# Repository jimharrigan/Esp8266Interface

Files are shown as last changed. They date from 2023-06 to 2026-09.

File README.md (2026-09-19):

# Esp8266Interface

A WiFi bridge between a dry-contact (or opto-isolated) signal and MQTT / HTTP, built
around an ESP-01 module. It reports the state of an external input to an MQTT topic
and/or a pair of webhook URLs, and drives a relay output in response to MQTT messages
or a polled URL.

Typical use is retrofitting network connectivity onto existing wired equipment —
a doorbell transformer, an alarm panel output, a gate contact — without modifying it.

The repository contains both halves of the project:

| Path | Contents |
| --- | --- |
| `Esp8266Interface.ino` | The Arduino firmware (single sketch) |
| `Esp8266Interface/` | KiCad schematic and PCB for the carrier board |
| `Esp8266Interface/production/` | Fabrication output: gerbers, BOM, positions, IPC netlist |
| `Esp8266Interface.sln`, `*.vcxproj` | Visual Studio + [Visual Micro](https://www.visualmicro.com/) project |
| `Esp8266Interface/test/` | Scratch KiCad project, not part of the build |

## How it works

**Input → network.** An external signal pulls `GPIO3` low, either through the on-board
PC817 optocoupler (from the `HV In` header) or by a plain contact closure on the `In3`
header. A pin-change interrupt records the new level; the main loop notices the change
and:

- publishes `Trigger` (pin low) or `Reset` (pin high) to the configured MQTT topic, and
- issues an HTTP `GET` to the configured trigger URL or reset URL.

**Network → output.** The firmware subscribes to a control topic. A payload of `1` or
`trigger` drives `GPIO1` high; anything else drives it low. `GPIO1` gates a 2N7000
low-side switch on the `Rly` header, so this is intended to energise a relay coil. The
new state is echoed back to the status topic as `Output 1` / `Output 0`.

The same output can instead — or as well — be driven by polling. If a control URL is
configured, the board fetches it every 2 s and looks at the reply: a body containing
`Trigger` closes the relay, one containing `Reset` opens it. This suits a far end that
has no MQTT broker and cannot reach in to the board, only be asked.

## Hardware

### Connectors

Silkscreen labels come from the BOM; the descriptions below are derived from the netlist.

| Ref | Label | Function |
| --- | --- | --- |
| J1 | `ESP01` | 2x4 socket for the ESP-01 module |
| J4 | `Pin` | **Power in.** Pin 1 GND, pin 2 raw DC into the LM1084-3.3 regulator |
| J5 | `Pout` | **Power out.** Pin 1 raw input rail, pin 2 regulated +3.3 V |
| J7 | `HV In` | **Isolated sense input.** Pin 1 is the common return; pin 2 feeds the optocoupler through R2 (1 k), pin 3 through R3 (68 k) + R2 for a higher-voltage source. D2 (1N4004) rectifies, so an AC source works; D1 (zener) and C5 clamp and smooth what reaches the PC817 LED via R1 (2.2 k) |
| J2 | `In3` | **Non-isolated input.** Shorting the two pins pulls `GPIO3` to GND, in parallel with the optocoupler |
| J3 | `In` | **Config-portal button.** Shorts `GPIO0` to `GPIO2`, which the firmware holds low after boot |
| J6 | `Rly` | **Relay output.** Pin 1 is the raw input rail, pin 2 the 2N7000 drain; D3 (1N4001) is the flyback diode across the coil |
| SW1 | — | Momentary **reset** for the ESP-01 (`RST` to GND) |

The zener D1 has no value in the BOM, so the usable voltage range of each `HV In` tap
depends on the part actually fitted. Work out the range for your source before relying
on it, and treat anything on `HV In` as hazardous unless you know otherwise — nothing on
the board isolates `HV In` from its own source, only from the ESP side.

### ESP-01 pin usage

| Pin | Direction | Use |
| --- | --- | --- |
| `GPIO0` | input, 3.3 k pull-up (R6) | Config-portal button, read in `loop()`; also the ESP-01 flash-mode strap |
| `GPIO1` | output | Relay drive, through R4 (47 k) into the 2N7000 gate. Also the UART TX pin |
| `GPIO2` | output, driven low | Return path for the `GPIO0` button, so the button cannot hold the board in flash mode at boot. 3.3 k pull-up (R5) |
| `GPIO3` | input, internal pull-up | Sense input, from the optocoupler or `In3`. Also the UART RX pin |

Two pins do double duty as the serial port, which shapes the firmware:

- `Serial.begin()` is called with `SERIAL_TX_ONLY` so `GPIO3` stays usable as an input.
- `GPIO1` cannot be the UART TX pin and the relay drive at the same time. The
  `DEBUG_SERIAL` switch at the top of the sketch picks one:

  | `DEBUG_SERIAL` | Behaviour |
  | --- | --- |
  | `0` (default) | Boot messages print, then `setup()` calls `Serial.end()` and claims `GPIO1` as an output. Logging stops; the relay works |
  | `1` | Serial logging stays on for the whole run; the relay output does nothing |

  Use `DBG_PRINT()` / `DBG_PRINTLN()` for any log line added after boot — plain
  `Serial` calls past the end of `setup()` go to a closed port in the default build.
- `GPIO1` toggles as TX during boot. C1 (33 µF) on the MOSFET gate with R4 gives roughly
  a 1.5 s time constant, which stops the relay chattering while the module starts up —
  at the cost of the output switching slowly.

## Building and flashing

The sketch targets the Arduino core for ESP8266 and needs these libraries:

- [WiFiManager](https://github.com/tzapu/WiFiManager) (tzapu)
- [ArduinoJson](https://arduinojson.org/) v6 — the sketch uses `DynamicJsonDocument`
- [PubSubClient](https://github.com/knolleary/pubsubclient)
- `LittleFS`, `ESP8266HTTPClient`, `WiFiClientSecure` — all part of the ESP8266 core

Build with the Arduino IDE, `arduino-cli`, or the supplied Visual Studio / Visual Micro
solution. Choose a flash layout that includes a LittleFS partition — the configuration
is stored in `/config.json` and there is nowhere to save settings without it.

The board has no USB interface and no auto-reset circuit. To flash, use an external
3.3 V USB-to-serial adapter on the ESP-01's `TX`/`RX`/`GND`, hold `GPIO0` low, and pulse
reset. Doing this with the module out of the socket avoids back-feeding the `Rly` and
`HV In` circuitry through `GPIO1` and `GPIO3`.

## Configuration

At boot the board tries the WiFi credentials WiFiManager has stored, giving up after
20 s. Failing to connect is not fatal — it keeps running while the ESP8266 keeps
retrying WiFi in the background — and it deliberately does **not** open the config
portal on its own, so a router outage cannot leave an access point running unattended
in someone's wall. If WiFi stays down for 5 minutes the board reboots (see
[Failure handling](#failure-handling)).

The portal is opened on demand instead. Press the button on `J3` and the board comes up
as an access point named **`ESP`** with the password **`1234567890`**, which is also how
you configure it on first boot, when nothing is stored yet. The portal offers the
standard WiFi and info pages plus a `param` page with these fields:

| Field | Stored as | Notes |
| --- | --- | --- |
| mqtt server | `mqtt_server` | Leave empty to disable MQTT entirely |
| mqtt port | `mqtt_port` | Defaults to 8883 |
| mqtt username | `mqtt_username` | |
| mqtt password | `mqtt_password` | |
| mqtt topic | `mqtt_topic` | Status topic the board publishes to |
| mqtt control topic | `mqtt_control_topic` | Subscribed topic for output commands; leave empty to skip |
| Trigger Url | `trigger_url` | Fetched when the input goes low, at boot if it is low, and every 10 minutes while it stays low |
| Reset Url | `reset_url` | Fetched when the input goes high, at boot if it is high, and every 10 minutes while it stays high |
| Control Url | `control_url` | Polled every 2 s for the output state; leave empty to skip |

Settings are written to `/config.json` in LittleFS and reloaded at boot. The portal
timeout is 300 s and runs non-blocking, so the rest of the loop keeps running while it
is open. Saving MQTT settings takes effect immediately: the client is re-pointed at the
new broker and any live session is dropped, so the next reconnect picks up the new
server, port, credentials and control topic without a restart.

### Messages

| Direction | Topic | Payload |
| --- | --- | --- |
| Published | `mqtt_topic` | `Trigger` when the input goes low, `Reset` when it goes high, and the current state each time the broker connection comes up |
| Published | `mqtt_topic` | `Output 1` / `Output 0` after a control message |
| Subscribed | `mqtt_control_topic` | `1` or `trigger` turns the output on; any other payload turns it off |

Payload matching is case-insensitive. An HTTP request counts as successful if the
server answers with any 2xx status; the response body is only read for the control URL.

### Control URL

A control URL is polled every 2 s and the reply decides where the output sits:

| Reply body | Effect |
| --- | --- |
| contains `Trigger` | Output on — relay energised |
| contains `Reset` | Output off |
| contains both | Treated as `Trigger` |
| contains neither | Output left as it is |
| request failed | Output left as it is |

The match is case-insensitive and anywhere in the body, so a page carrying other
markup around the word still works. Only `Output 1` / `Output 0` transitions are
published to the status topic — a poll that finds the same state as last time is
silent, so a 2 s poll does not flood the broker.

Nothing about the poll reboots the board: a control URL that stops answering leaves
the relay where it was rather than dropping it, and the next poll tries again. The
request timeout is 1.5 s, under the 2 s interval, so an unreachable server cannot
stall the loop for longer than one period, and the interval is measured from the end
of each request rather than the start. The poll runs on the first pass through the
loop, so a reboot picks the output back up immediately instead of waiting, and is
held off entirely while the config portal is open, so a bad URL can still be
corrected.

Note that the request is plain HTTP over `WiFiClient` — an `https://` control URL will
not work, and the reply is trusted as-is.

MQTT runs over `WiFiClientSecure`, but `setInsecure()` is called, so the server
certificate is not validated. Credentials are stored in plaintext in the filesystem.
Treat this as suitable for a trusted LAN, not the open internet.

### Failure handling

The input is read at boot, so its state is sent even if it never changes: the matching
URL on the first pass through the loop, and the MQTT status as soon as the broker
connects.

- **URL request fails** (no WiFi, no connection, or a non-2xx reply): the next attempt
  is due 30 s later instead of 10 minutes, and when it comes due the board reboots
  instead. After the reboot it reads the input again and makes a fresh attempt.
- **WiFi down for 5 minutes:** the board reboots. The timer counts from power-up if WiFi
  never connects, so a board with no stored credentials reboots every 5 minutes until
  the portal is used.
- **MQTT disconnected:** reconnects every 5 s, but only while WiFi is up. MQTT failures
  never cause a reboot.

Neither reboot happens while the config portal is open, and the 5-minute WiFi timer
starts again when the portal closes. A reboot turns the output off until a control
message arrives; a retained control message restores it as soon as MQTT reconnects, and
a control URL restores it on the first poll.

On the ESP8266 the first software restart after a serial upload can hang in the
bootloader, so power-cycle the board once after flashing.

## Notes

The sketch compiles clean — no warnings — against ESP8266 core 3.1.2 with
`--warnings all`, in both `DEBUG_SERIAL` configurations.

A few behaviours are deliberate rather than oversights:

- The config portal opens on the button's falling edge, not while it is held, and not
  on top of a portal that is already running. It never opens by itself on a failed
  connection.
- MQTT connection attempts are spaced `MQTT_RECONNECT_INTERVAL` (5 s) apart and
  skipped while WiFi is down, so they do not stall the loop. Saving settings in the
  portal resets that, so a new broker is tried on the next pass.
- `publishMessage()` honours its `retained` argument; every call site passes `true`, so
  every status message is retained.
- Both output paths go through `SetOutput()`, so they share one idea of where the
  output is. An MQTT command is acknowledged on the status topic whether or not it
  changed anything; a control URL poll only publishes when the level actually moves.
- If both a control topic and a control URL are configured, they fight: whichever
  spoke last wins, and the URL speaks every 2 s. Configure one or the other.

## License

GPL-3.0 — see [LICENSE](LICENSE).

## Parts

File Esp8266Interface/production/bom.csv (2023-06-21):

Designator | Footprint | Quantity | Value | LCSC Part #
C1 | CP_Radial_D5.0mm_P2.00mm | 1 | 33UF
C2, C4 | C_Disc_D3.8mm_W2.6mm_P2.50mm | 2 | .01
C3 | CP_Radial_D5.0mm_P2.00mm | 1 | 10UF
C5 | CP_Radial_D5.0mm_P2.00mm | 1 | 22UF
D1 | D_A-405_P5.08mm_Vertical_AnodeUp | 1 | D_Zener
D2 | D_DO-41_SOD81_P5.08mm_Vertical_KathodeUp | 1 | 1N4004
D3 | D_DO-41_SOD81_P3.81mm_Vertical_KathodeUp | 1 | 1N4001
J1 | PinHeader_2x04_P2.54mm_Vertical | 1 | ESP01
J2 | PinHeader_1x02_P2.54mm_Vertical | 1 | In3
J3 | PinHeader_1x02_P2.54mm_Vertical | 1 | In
J4 | PinHeader_1x02_P2.54mm_Vertical | 1 | Pin
J5 | PinHeader_1x02_P2.54mm_Vertical | 1 | Pout
J6 | PinHeader_1x02_P2.54mm_Vertical | 1 | Rly
J7 | PinHeader_1x03_P2.54mm_Vertical | 1 | HV In
Q1 | TO-92_Inline | 1 | 2N7000
R1 | R_Axial_DIN0207_L6.3mm_D2.5mm_P2.54mm_Vertical | 1 | 2.2k
R2 | R_Axial_DIN0207_L6.3mm_D2.5mm_P2.54mm_Vertical | 1 | 1k
R3 | R_Axial_DIN0309_L9.0mm_D3.2mm_P2.54mm_Vertical | 1 | 68K
R4 | R_Axial_DIN0207_L6.3mm_D2.5mm_P2.54mm_Vertical | 1 | 47K
R5, R6 | R_Axial_DIN0207_L6.3mm_D2.5mm_P2.54mm_Vertical | 2 | 3.3K
SW1 | SW_Tactile_Straight_KSL0Axx1LFTR | 1 | SW_Push
U1 | TO-220-3_Horizontal_TabDown | 1 | LM1084-3.3
U2 | DIP-4_W7.62mm | 1 | PC817

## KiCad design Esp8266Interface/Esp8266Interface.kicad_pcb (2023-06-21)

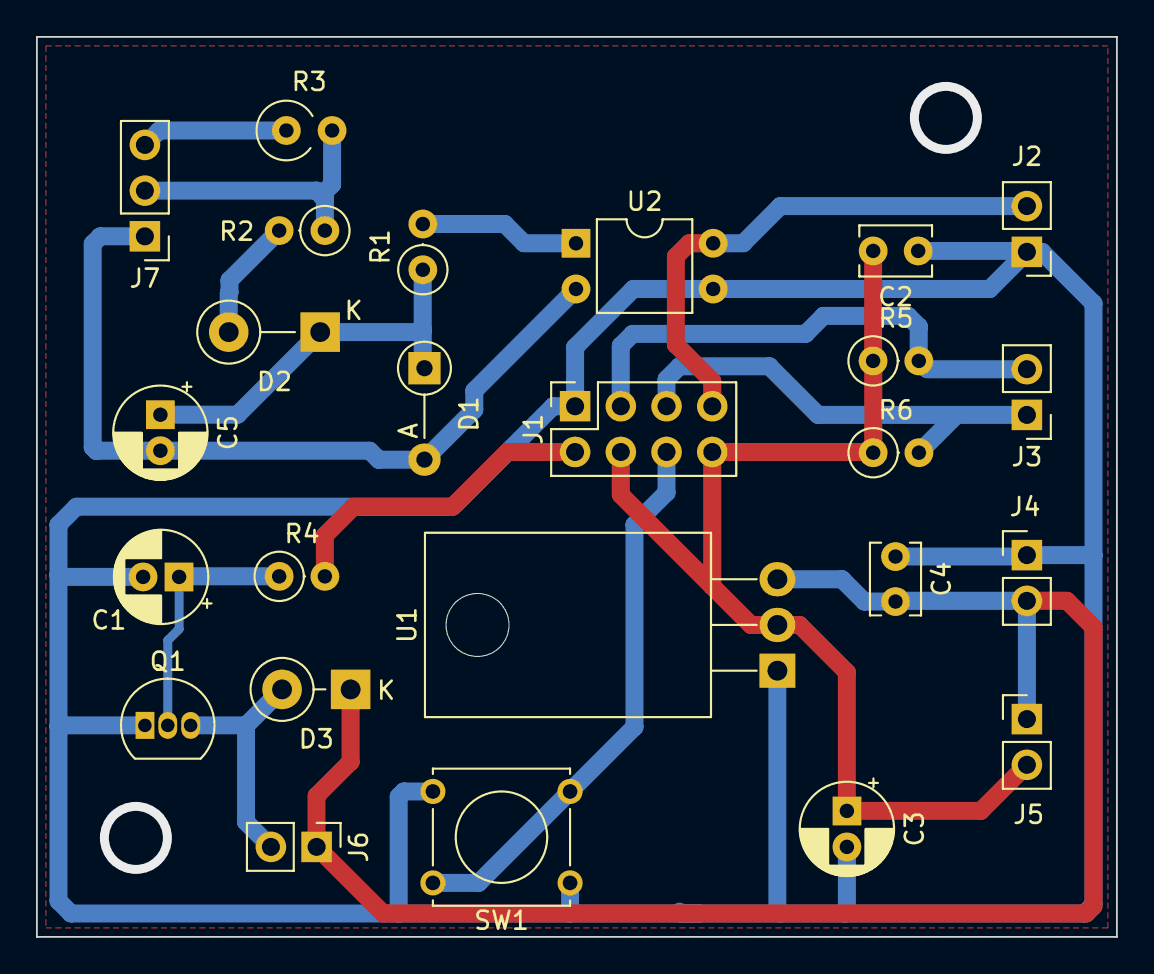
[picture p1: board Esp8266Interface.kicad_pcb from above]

Board: 2 copper layers, 60.0 x 50.0 mm, 25 parts (0 on the bottom side), 16 nets.

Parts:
C1: 33UF; CP_Radial_D5.0mm_P2.00mm
C2, C4: .01; C_Disc_D3.8mm_W2.6mm_P2.50mm
C3: 10UF; CP_Radial_D5.0mm_P2.00mm
C5: 22UF; CP_Radial_D5.0mm_P2.00mm
D1: D_Zener; D_A-405_P5.08mm_Vertical_AnodeUp
D2: 1N4004; D_DO-41_SOD81_P5.08mm_Vertical_KathodeUp
D3: 1N4001; D_DO-41_SOD81_P3.81mm_Vertical_KathodeUp
J1: ESP01; PinHeader_2x04_P2.54mm_Vertical
J2: In3; PinHeader_1x02_P2.54mm_Vertical
J3: In; PinHeader_1x02_P2.54mm_Vertical
J4: Pin; PinHeader_1x02_P2.54mm_Vertical
J5: Pout; PinHeader_1x02_P2.54mm_Vertical
J6: Rly; PinHeader_1x02_P2.54mm_Vertical
J7: HV In; PinHeader_1x03_P2.54mm_Vertical
Q1: 2N7000; TO-92_Inline
R1: 2.2k; R_Axial_DIN0207_L6.3mm_D2.5mm_P2.54mm_Vertical
R2: 1k; R_Axial_DIN0207_L6.3mm_D2.5mm_P2.54mm_Vertical
R3: 68K; R_Axial_DIN0309_L9.0mm_D3.2mm_P2.54mm_Vertical
R4: 47K; R_Axial_DIN0207_L6.3mm_D2.5mm_P2.54mm_Vertical
R5, R6: 3.3K; R_Axial_DIN0207_L6.3mm_D2.5mm_P2.54mm_Vertical
SW1: SW_Push; SW_Tactile_Straight_KSL0Axx1LFTR
U1: LM1084-3.3; TO-220-3_Horizontal_TabDown
U2: PC817; DIP-4_W7.62mm

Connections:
+3.3V: C2.2, C3.1, J1.4 (CH_PD), J1.8 (Vcc), J5.2, R5.1, R6.1, U1.2 (VO)
GND: C1.2, C2.1, C3.2, C4.1, J1.1 (GND), J2.1, J4.1, Q1.1 (S), SW1.2, U1.1 (GND), U2.3
unnamed: C5.2, D1.2 (A), J7.1, U2.2
unnamed: C5.1, D1.1 (K), D2.1 (K), R1.1
unnamed: D2.2 (A), R2.2
unnamed: D3.2 (A), J6.2, Q1.3 (D)
unnamed: C4.2, D3.1 (K), J4.2, J5.1, J6.1, U1.3 (VI)
unnamed: J1.5 (GPIO0), J3.1, R6.2
unnamed: J1.2 (GPIO1), R4.2
unnamed: J1.3 (GPIO2), J3.2, R5.2
unnamed: J1.7 (GPIO3), J2.2, U2.4
unnamed: J1.6 (Reset), SW1.1
unnamed: J7.2, R2.1, R3.2
unnamed: J7.3, R3.1
unnamed: C1.1, Q1.2 (G), R4.1
unnamed: R1.2, U2.1

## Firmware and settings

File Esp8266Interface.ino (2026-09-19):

#include <Arduino.h>
#include <FS.h>
#include <LittleFS.h>

#define start_portal_pin 0
#define output_pin 1
#define control_pin 2
#define input_pin 3

// output_pin (GPIO1) is also the UART TX pin, so serial logging and the output
// cannot both have it. Set DEBUG_SERIAL to 1 to keep logging for the whole run
// and leave the output dead, or 0 to release the UART at the end of setup() so
// the output can be driven. Boot messages are printed either way.
#define DEBUG_SERIAL 0

#if DEBUG_SERIAL
#define DBG_PRINT(x)   Serial.print(x)
#define DBG_PRINTLN(x) Serial.println(x)
#else
#define DBG_PRINT(x)
#define DBG_PRINTLN(x)
#endif

#ifdef ESP8266
#include <ESP8266WiFi.h>
#include <ESP8266HTTPClient.h>
#else
#include <WiFi.h>
#endif

#include <WiFiManager.h> // https://github.com/tzapu/WiFiManager
#include <ArduinoJson.h>
#include <PubSubClient.h>
#include <WiFiClientSecure.h>



// How long to wait between MQTT connection attempts. The initial value sits one
// interval in the past so the first attempt is not delayed.
#define MQTT_RECONNECT_INTERVAL 5000UL
unsigned long lastReconnectAttempt = (unsigned long)0 - MQTT_RECONNECT_INTERVAL;

// The trigger/reset urls are re-sent this often even when the input has not
// changed, so the far end keeps hearing the current state. setup() backdates the
// timer so the first request goes out as soon as loop() starts.
#define URL_REPEAT_INTERVAL 600000UL
unsigned long lastUrlRequest = 0;

// A request that does not get through (WiFi down, server unreachable, or a
// non-2xx reply) is followed up after this much shorter wait rather than at the
// next ten-minute repeat. The follow-up reboots the board before trying again;
// see SendStateUrl().
#define URL_RETRY_INTERVAL 30000UL
unsigned long urlRequestInterval = URL_REPEAT_INTERVAL;
bool lastUrlRequestFailed = false;

// How often the control url is polled, when one is configured. A poll is a
// blocking request, so the timeout is held below the interval to stop an
// unreachable server from stalling the loop for longer than one period.
// setup() backdates the timer so the first poll goes out as soon as loop()
// starts, which is what picks the output back up after a reboot.
#define CONTROL_URL_INTERVAL 2000UL
#define CONTROL_URL_TIMEOUT 1500UL
unsigned long lastControlUrlRequest = 0;

// The board reboots once WiFi has been down for this long. The timer starts at
// zero, so a board that never connects after power-up counts from boot.
#define WIFI_DOWN_REBOOT_INTERVAL 300000UL
unsigned long lastWifiConnected = 0;

// A contact closing or opening rattles for a few milliseconds, and every one of
// those edges raises an interrupt. The level has to hold steady for this long
// before the main loop treats it as a real change, so one flick of the input
// produces one message instead of a burst of them.
#define DEBOUNCE_INTERVAL 50UL

bool portalButtonWasPressed = false;
bool shouldSaveConfig = false;
// The debounced level the rest of the sketch acts on. setup() replaces this with
// the real level before loop() starts.
bool inputValue = 1;
// Written by the interrupt handler on every edge, bounces included, along with
// the time that edge arrived. Both are volatile because the main loop reads what
// the handler writes.
volatile bool rawInputValue = 1;
volatile unsigned long lastEdgeTime = 0;
// The level the output is being held at. Tracked so the polled control url can
// tell a real change from a repeat of the level it already set.
bool outputValue = 0;
char mqtt_server[64] = "";
int mqtt_port = 8883;
char mqtt_username[32] = "";
char mqtt_password[32] = "";
char mqtt_topic[32] = "";
char mqtt_control_topic[32] = "";
char trigger_url[64] = "";
char reset_url[64] = "";
char control_url[64] = "";

WiFiManagerParameter custom_mqtt_server("server", "mqtt server", "", 63);
WiFiManagerParameter custom_mqtt_port("port", "mqtt port", "", 6);
WiFiManagerParameter custom_mqtt_user("user", "mqtt username", "", 31);
WiFiManagerParameter custom_mqtt_password("password", "mqtt password", "", 31);
WiFiManagerParameter custom_mqtt_topic("topic", "mqtt topic", "", 31);
WiFiManagerParameter custom_mqtt_control_topic("control", "mqtt control topic", "", 31);
WiFiManagerParameter custom_trigger_url("triggerurl", "Trigger Url", "", 63);
WiFiManagerParameter custom_reset_url("reseturl", "Reset Url", "", 63);
WiFiManagerParameter custom_control_url("controlurl", "Control Url", "", 63);

/**** Secure WiFi Connectivity Initialisation *****/
WiFiClientSecure espClient;
WiFiManager wm;

// Records the input level and the moment it changed on every edge. The main loop
// does the debouncing, so this stays short. millis() is IRAM_ATTR in the esp8266
// core and is safe to call from here.
IRAM_ATTR void interruptHandler() {
  rawInputValue = digitalRead(input_pin);
  lastEdgeTime = millis();
}

/**** MQTT Client Initialisation Using WiFi Connection *****/
PubSubClient client(espClient);

/************* Connect to MQTT Broker ***********/
void reconnect() {
    if(!client.connected()) {
        DBG_PRINT("Attempting MQTT connection...");
        DBG_PRINT("mqtt_username=");
        DBG_PRINT(mqtt_username);
        DBG_PRINT("|");
        String clientId = "ESP8266Client-";   // Create a random client ID
        clientId += String(random(0xffff), HEX);
        // Attempt to connect
        if (client.connect(clientId.c_str(), mqtt_username, mqtt_password)) {
            DBG_PRINTLN("connected");

            if(strlen(mqtt_control_topic) > 0)
            {
                DBG_PRINT("Going to save->");
                DBG_PRINT(mqtt_control_topic);
                client.subscribe(mqtt_control_topic);   // subscribe the topics here
                DBG_PRINTLN("<-Done.");
            }

            // Anything that changed while the connection was down was never
            // published, so bring the retained state up to date now.
            publishMessage(mqtt_topic, inputValue ? "Reset" : "Trigger", true);

        }
        else {
            DBG_PRINT("failed, rc=");
            DBG_PRINT(client.state());
        }
    }
}

void SaveConfig()
{
    //Serial.println("Saving config...");

    JsonDocument json;

    json["mqtt_server"] = mqtt_server;
    json["mqtt_port"] = mqtt_port;
    json["mqtt_username"] = mqtt_username;
    json["mqtt_password"] = mqtt_password;
    json["mqtt_topic"] = mqtt_topic;
    json["mqtt_control_topic"] = mqtt_control_topic;
    json["trigger_url"] = trigger_url;
    json["reset_url"] = reset_url;
    json["control_url"] = control_url;
    
    if (!LittleFS.begin()) {
        //Serial.println("LittleFS Mount Failed");
        return;
    }
    File configFile = LittleFS.open("/config.json", "w");
    if (!configFile) {
        //Serial.println("failed to open config file for writing");
    }

#if DEBUG_SERIAL
    serializeJson(json, Serial);
#endif
    serializeJson(json, configFile);
    configFile.close();
    LittleFS.end();
    //end save

}

// Copy one string field out of the config document. The destination is left
// alone if the key is missing or is not a string, and an over-long value in the
// file is truncated rather than allowed to run off the end of the buffer.
static void LoadString(JsonDocument& json, const char* key, char* dest, size_t size)
{
    const char* value = json[key];
    if (value != nullptr)
    {
        strlcpy(dest, value, size);
    }
}

void LoadConfig()
{
    //Serial.println("Loading Config...");

    ////Serial.println(custom_mqtt_server.getValue());

    //read configuration from FS json
    //Serial.println("mounting FS...");

    if (LittleFS.begin()) {
        //Serial.println("mounted file system");
        if (LittleFS.exists("/config.json")) {
            //file exists, reading and loading
            //Serial.println("reading config file");
            File configFile = LittleFS.open("/config.json", "r");
            if (configFile) {
                //Serial.println("opened config file");
                JsonDocument json;
                auto deserializeError = deserializeJson(json, configFile);
#if DEBUG_SERIAL
                serializeJson(json, Serial);
#endif
                if (!deserializeError) {
                    //Serial.println("\nparsed json");

                    // A missing key leaves the field at its compiled-in default,
                    // so a config.json from an older build loads what it does
                    // have instead of faulting on the keys it lacks.
                    LoadString(json, "mqtt_server", mqtt_server, sizeof(mqtt_server));
                    mqtt_port = json["mqtt_port"] | mqtt_port;
                    LoadString(json, "mqtt_username", mqtt_username, sizeof(mqtt_username));
                    LoadString(json, "mqtt_password", mqtt_password, sizeof(mqtt_password));
                    LoadString(json, "mqtt_topic", mqtt_topic, sizeof(mqtt_topic));
                    LoadString(json, "mqtt_control_topic", mqtt_control_topic, sizeof(mqtt_control_topic));
                    LoadString(json, "trigger_url", trigger_url, sizeof(trigger_url));
                    LoadString(json, "reset_url", reset_url, sizeof(reset_url));
                    LoadString(json, "control_url", control_url, sizeof(control_url));
                }
                else
                {
                    //Serial.println("failed to load json config");
                }
                configFile.close();
            }
        }
        LittleFS.end();
    }
    else {
        //Serial.println("failed to mount FS");

        //Try to format so we can save later
        if(LittleFS.format())
        {
          //Serial.println("Format complete");
        }
        else
        {
          //Serial.println("Format failed");
        }
    }
    //end read
}

void saveParamCallback() {
    //Serial.println("saveParamCallback()");
    shouldSaveConfig = true;
}

// Drives the output and echoes the new level to the status topic. Both control
// paths go through here so they share one idea of where the output is. An
// explicit MQTT command is acknowledged whether or not it changed anything; the
// polled control url repeats the same level every couple of seconds, so it only
// publishes when the level actually moves.
void SetOutput(bool value, bool alwaysPublish)
{
    bool changed = value != outputValue;

    outputValue = value;
    digitalWrite(output_pin, value);

    if (changed || alwaysPublish)
    {
        publishMessage(mqtt_topic, value ? "Output 1" : "Output 0", true);
    }
}

/***** Call back Method for Receiving MQTT messages and Switching LED ****/

void mqttCallback(char* topic, byte* payload, unsigned int length) {
  
    String incommingMessage = "";
    for (unsigned int i = 0; i < length; i++) incommingMessage += (char)payload[i];

    DBG_PRINTLN("Message arrived [" + String(topic) + "]" + incommingMessage);
    incommingMessage.toLowerCase();
    //--- check the incomming message
    if (String(topic).equals(mqtt_control_topic)) {
        if (incommingMessage.equals("1") || incommingMessage.equals("trigger") )
        {
            //Serial.println("TRIGGER CONTROL!!!");
            SetOutput(1, true);
        }
        else
        {
          //Serial.println("RESET control");
          SetOutput(0, true);
        }
    }

}

// Returns true when the server answered with a 2xx status; no WiFi, a
// connection failure (negative httpCode) or a non-2xx status is a failure.
// A caller that cares what the server said passes a string for the body, which
// is filled in on success and emptied on failure; passing nullptr skips reading
// it. timeout bounds the connect and the read, so a server that accepts the
// connection and then goes quiet cannot hold up the loop indefinitely.
bool MakeRequest(String url, String* body, unsigned long timeout)
{
    bool success = false;

    if (body != nullptr)
    {
        *body = "";
    }

    if (WiFi.status() == WL_CONNECTED) { //Check the current connection status
        ////Serial.println("WiFi is connected");
        WiFiClient wiFiClient;
        HTTPClient http;

        http.setTimeout(timeout);
        http.begin(wiFiClient, url);
        ////Serial.print("Requesting:");
        ////Serial.println(url);
        int httpCode = http.GET();  //Make the request

        success = httpCode >= 200 && httpCode < 300;

        if (success && body != nullptr)
        {
            *body = http.getString();
        }

        http.end(); //Free the resources
    }

    return success;
}

// Fire-and-forget form, for the trigger and reset urls: any endpoint that
// accepts the request counts as a success and the body is never read.
bool MakeRequest(String url)
{
    return MakeRequest(url, nullptr, HTTPCLIENT_DEFAULT_TCP_TIMEOUT);
}

// Requests the url matching the current input level and restarts the repeat
// timer, so a repeat always lands a full interval after the last request,
// whether that came from an edge or from the timer itself. A failed request
// shortens the wait to the retry interval.
//
// If the previous request failed, the board is rebooted instead of trying
// again, clearing whatever state the WiFi stack or network client is stuck in.
// The flag lives in RAM, so the reboot clears it; setup() then reads the input
// and the first pass through loop() makes a real attempt. That attempt reboots
// only if it fails and another retry interval goes by. The reboot is skipped
// while the config portal is up, so it cannot be closed in the middle of use.
void SendStateUrl()
{
    if (lastUrlRequestFailed && !wm.getConfigPortalActive())
    {
        ESP.restart();
    }

    lastUrlRequest = millis();

    const char* url = inputValue ? reset_url : trigger_url;

    if(strlen(url) == 0)
    {
        lastUrlRequestFailed = false;
        urlRequestInterval = URL_REPEAT_INTERVAL;
        return;
    }

    //Serial.println(inputValue ? "Requesting reset_url" : "Requesting trigger_url");
    lastUrlRequestFailed = !MakeRequest(url);
    urlRequestInterval = lastUrlRequestFailed ? URL_RETRY_INTERVAL : URL_REPEAT_INTERVAL;
}

// Asks the control url what the output should be doing and does what it says.
// "Trigger" anywhere in the reply closes the relay and "Reset" opens it;
// matching is case-insensitive and the rest of the body is ignored, so a page
// carrying other text still works. A reply holding both words is taken as a
// trigger. A reply holding neither, or a request that does not get through,
// leaves the output where it is and the next poll tries again - unlike the
// state urls, a failure here neither reboots the board nor drops the relay,
// because the far end going quiet for a moment is not a command.
void PollControlUrl()
{
    String body;
    bool success = MakeRequest(control_url, &body, CONTROL_URL_TIMEOUT);

    // Timed from the end of the request rather than the start, so a slow or
    // timing-out server spaces the polls out instead of running them back to
    // back.
    lastControlUrlRequest = millis();

    if (!success)
    {
        return;
    }

    body.toLowerCase();

    if (body.indexOf("trigger") >= 0)
    {
        SetOutput(1, false);
    }
    else if (body.indexOf("reset") >= 0)
    {
        SetOutput(0, false);
    }
}

/**** Method for Publishing MQTT Messages **********/
void publishMessage(const char* topic, String payload, boolean retained) {
    if (client.publish(topic, payload.c_str(), retained))
    {
        DBG_PRINTLN("Message publised [" + String(topic) + "]: " + payload);
    }
    else
    {
      DBG_PRINTLN("Failed to publish MQTT message.");
    }
}
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
void loop() {

    wm.process(); // avoid delays() in loop when non-blocking and other long running code

    // Act on the press itself rather than on every pass while the button is
    // held, and never on top of a portal that is already up. The return value is
    // not a success flag here: the portal is non-blocking, so startConfigPortal()
    // returns the not-yet-connected state immediately.
    bool portalButtonPressed = !digitalRead(start_portal_pin);

    if (portalButtonPressed && !portalButtonWasPressed && !wm.getConfigPortalActive())
    {
        DBG_PRINTLN("Starting config portal.");
        wm.startConfigPortal("ESP", "1234567890");
    }

    portalButtonWasPressed = portalButtonPressed;

    // Reboot once WiFi has been gone for too long, in case the WiFi stack has
    // wedged rather than the network simply being down. An open config portal
    // counts as connected, so the portal is never closed mid-use and a full
    // interval is allowed after it closes. Comparing the difference keeps this
    // correct across the 49-day millis() rollover.
    if (WiFi.status() == WL_CONNECTED || wm.getConfigPortalActive())
    {
        lastWifiConnected = millis();
    }
    else if (millis() - lastWifiConnected >= WIFI_DOWN_REBOOT_INTERVAL)
    {
        ESP.restart();
    }

    if (shouldSaveConfig)
    {
        strcpy(mqtt_server, custom_mqtt_server.getValue());
        mqtt_port = atoi(custom_mqtt_port.getValue());
        DBG_PRINTLN(mqtt_port);
        strcpy(mqtt_username, custom_mqtt_user.getValue());
        strcpy(mqtt_password, custom_mqtt_password.getValue());
        strcpy(mqtt_topic, custom_mqtt_topic.getValue());
        strcpy(mqtt_control_topic, custom_mqtt_control_topic.getValue());
        strcpy(trigger_url, custom_trigger_url.getValue());
        strcpy(reset_url, custom_reset_url.getValue());
        strcpy(control_url, custom_control_url.getValue());

        SaveConfig();
        shouldSaveConfig = false;

        // Re-point the client at what was just saved. setServer() keeps the port
        // by value, so a port change is invisible without this call, and drop any
        // live session so the next reconnect() picks up the new broker,
        // credentials and control topic instead of waiting for a reboot.
        client.setServer(mqtt_server, mqtt_port);
        if (client.connected())
        {
            client.disconnect();
        }

        // Reconnect on the next pass rather than after the backoff interval, so
        // saving settings visibly takes effect. Backdating from millis() keeps
        // this correct across the 49-day rollover.
        lastReconnectAttempt = millis() - MQTT_RECONNECT_INTERVAL;
    }

    if(strlen(mqtt_server) > 0 )
    {
        if (!client.connected())
        {
            // Space the attempts out, so an unreachable broker is retried every
            // few seconds rather than as fast as connect() can time out. Without
            // WiFi an attempt cannot succeed and would only stall the loop, so
            // hold off; the timer is left alone, so the first pass after WiFi
            // returns tries straight away.
            if (WiFi.status() == WL_CONNECTED &&
                millis() - lastReconnectAttempt >= MQTT_RECONNECT_INTERVAL)
            {
                lastReconnectAttempt = millis();
                reconnect();
            }
        }
        client.loop();
    }

    // A poll blocks for as long as the request takes, so it is held off while
    // the config portal is up: an unreachable control url would otherwise stall
    // the loop for most of every interval and leave the portal too sluggish to
    // correct it with. Comparing the difference keeps this correct across the
    // 49-day millis() rollover, as elsewhere in the loop.
    if(strlen(control_url) > 0 && !wm.getConfigPortalActive() &&
       millis() - lastControlUrlRequest >= CONTROL_URL_INTERVAL)
    {
        PollControlUrl();
    }

    //Serial.print(inputValue);
    //Serial.println(inputValue ? " Reset" : " Trigger");
    // Take a consistent pair: an edge landing between these two reads would
    // otherwise pair a new level with the previous edge's timestamp and let a
    // bounce through.
    noInterrupts();
    bool pendingValue = rawInputValue;
    unsigned long pendingEdgeTime = lastEdgeTime;
    interrupts();

    // Accept the new level only once it has sat still for the debounce interval.
    // While the input is still rattling every bounce pushes lastEdgeTime forward
    // and restarts the wait, so nothing is sent until it settles, and the level
    // that gets reported is the one it settled on.
    if(pendingValue != inputValue && millis() - pendingEdgeTime >= DEBOUNCE_INTERVAL)
    {
        inputValue = pendingValue;

        if(client.connected())
        {
            publishMessage(mqtt_topic, inputValue ? "Reset" : "Trigger", true);
        }

        SendStateUrl();
    }
    else if (millis() - lastUrlRequest >= urlRequestInterval)
    {
        // No edge for a while, so repeat whichever url matches the current
        // state, or retry sooner if the last request failed. Comparing the
        // difference keeps this correct across the 49-day millis() rollover.
        SendStateUrl();
    }
}

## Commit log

2023-06-19 Add KiCad files
    [Esp8266Interface.kicad_pcb, Esp8266Interface.kicad_sch, bom.csv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]
2023-06-21 Circuit board
    [Esp8266Interface.kicad_pcb, Esp8266Interface.kicad_sch, bom.csv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]
2025-06-02 Change to use interrupts to detect changes for input_pin + old uncommitted changes
2026-09-11 Fix output pin, HTTP trigger, config loading and WiFi connect
    Four defects that each disabled or crashed a documented feature:
    Relay output never drove. GPIO1 is both the UART TX pin and the MOSFET
    gate, so pinMode(output_pin, OUTPUT) had been commented out and
    digitalWrite() on it did nothing. Make the tradeoff an explicit
    DEBUG_SERIAL switch: 0 (default) prints boot messages then calls
    Serial.end() and claims GPIO1 as an output, 1 keeps logging for the whole
    run and leaves the output dead. Log calls that run after boot now use
    DBG_PRINT/DBG_PRINTLN so they compile out rather than write to a closed
    port.
    Trigger and reset URLs never fired. MakeRequest() gated on
    WiFiMulti.run() == WL_CONN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
    [Esp8266Interface.ino]
2026-09-11 Apply saved MQTT settings without a reboot
    client.setServer() ran only in setup(), so changes made in the config
    portal did not fully take hold until a restart. The effect was
    inconsistent rather than uniformly stale: setServer(const char*, uint16_t)
    stores the domain pointer rather than a copy, and mqtt_server is a global
    buffer, so a hostname change was picked up by accident on the next
    reconnect while the port, kept by value, was not. Changing the broker to a
    host on a different port therefore reconnected to the new host on the old
    Call setServer() again after SaveConfig() and disconnect any live session,
    so the next reconnect() applies the new server, port, credentials and
    control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
    [Esp8266Interface.ino]
2026-09-11 Clear remaining rough edges and all compile warnings
    Config portal is now edge triggered. It was started from inside loop() on
    every pass while the button was held; WiFiManager self-guards on
    configPortalActive, but _begin() still ran each time. Fire on the falling
    edge only, skip when getConfigPortalActive(), and ignore the return value:
    with a non-blocking portal startConfigPortal() returns early with the
    not-yet-connected state, so the old else branch read it backwards. Retires
    startPortalPending, which was assigned but never read.
    publishMessage() passes its retained argument through to client.publish()
    instead of a hardcoded true. All three call sites pass true, so behaviour
    is unchang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
    [Esp8266Interface.ino]
2026-09-12 Repeat the trigger/reset url every 10 minutes
    The urls were only requested on an input edge, so a receiver that missed one,
    restarted, or came up after the change had no way to learn the current state.
    Pull both requests into SendStateUrl() and call it from the loop when the input
    has been quiet for URL_REPEAT_INTERVAL, so the current state keeps being sent.
    The timer restarts on every send, whether from an edge or from the repeat
    itself, so a real change pushes the next repeat out a full interval instead of
    firing one right behind it. It starts at zero, putting the first repeat ten
    minutes after boot and leaving the previous no-request-at-startup behaviour
    intact. MQTT publishing is unchan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
    [Esp8266Interface.ino]
2026-09-12 Debounce the input before acting on a change
    A contact closing or opening rattles for a few milliseconds and every one of
    those edges raised an interrupt, so one flick of the input produced a burst of
    MQTT messages and url requests instead of one.
    Leave the handler recording just the raw level and the time the edge arrived,
    and move the decision into the loop: a new level is accepted only once it has
    held steady for DEBOUNCE_INTERVAL. While the input is still rattling each bounce
    pushes the edge time forward and restarts the wait, so nothing is sent until it
    settles and the level reported is the one it settled on. A bounce that returns
    to the original level sends nothing at all.
    The pair i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
    [Esp8266Interface.ino]
2026-09-14 Recover from WiFi and send failures, and report state at boot
    Losing WiFi had no handling of its own: reconnecting was left to the ESP8266
    core, and anything that happened during the outage was dropped. A state change
    made while offline reached the url only at the next ten-minute repeat, was never
    published over MQTT, and reconnect() kept blocking the loop on attempts that
    could not succeed.
    - reconnect() publishes the current state as soon as the broker connection
    comes up, so the retained topic is never left stale after an outage.
    - MQTT reconnects are skipped while WiFi is down. The timer is left alone, so
    the first pass after WiFi returns tries straight away.
    - MakeRequest() counts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
    [Esp8266Interface.ino]
2026-09-19 Drive the output from a polled control url
    The output could only be commanded over MQTT, which needs a broker and needs
    the far end to be able to reach in to the board. A control url inverts that:
    the board asks, every 2 s, and does what the reply says.
    A body containing Trigger closes the relay and one containing Reset opens it.
    The match is case-insensitive and anywhere in the body, as the MQTT payload
    match already is, so a page carrying other markup around the word works. A
    reply holding both words is taken as a trigger; one holding neither leaves the
    output alone.
    MakeRequest() gains a form that hands back the body and takes a timeout. The
    old single-argument form delegates to it with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
    [Esp8266Interface.ino]
